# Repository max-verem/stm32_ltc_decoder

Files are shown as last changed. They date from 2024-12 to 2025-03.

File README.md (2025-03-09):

# stm32_ltc_decoder

This device used for decoding LTC from VTRs or other sources. Output sent to CDC serial.

## used parts

### STM32 BluePill board

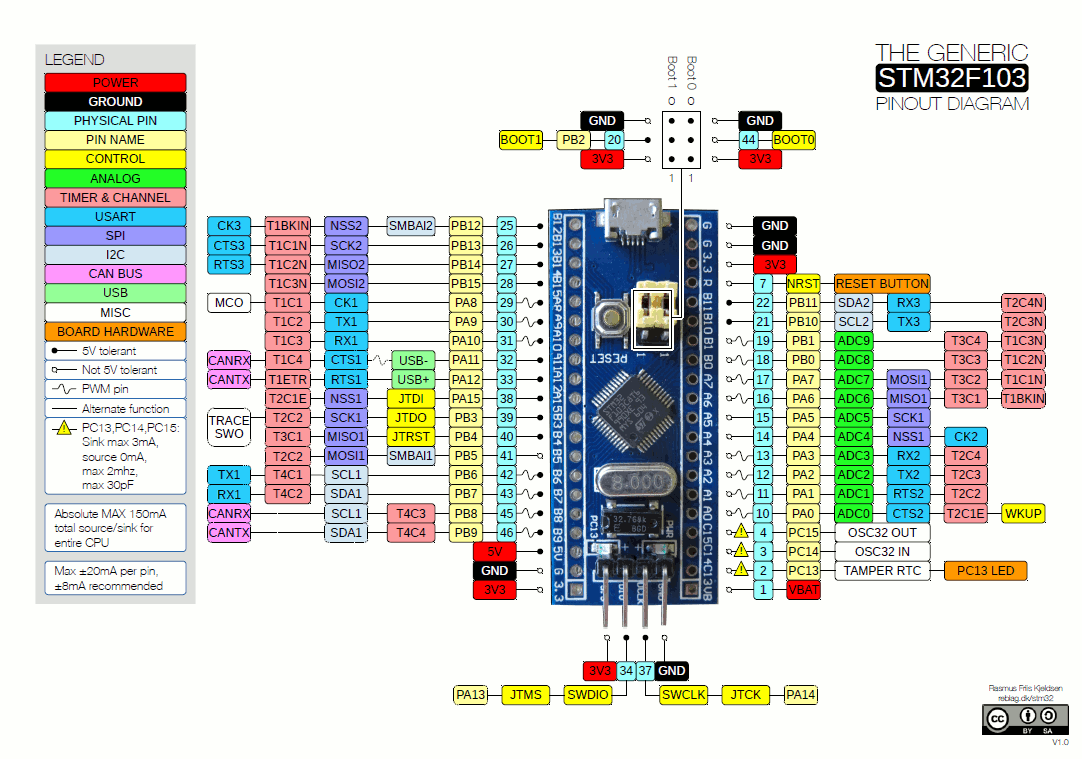
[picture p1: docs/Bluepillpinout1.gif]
STM32 BluePill board


### RS485 module

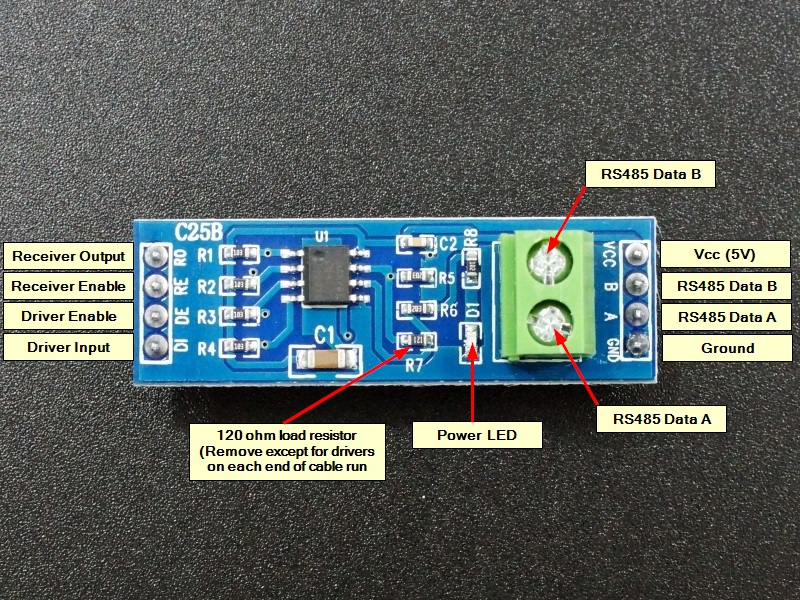
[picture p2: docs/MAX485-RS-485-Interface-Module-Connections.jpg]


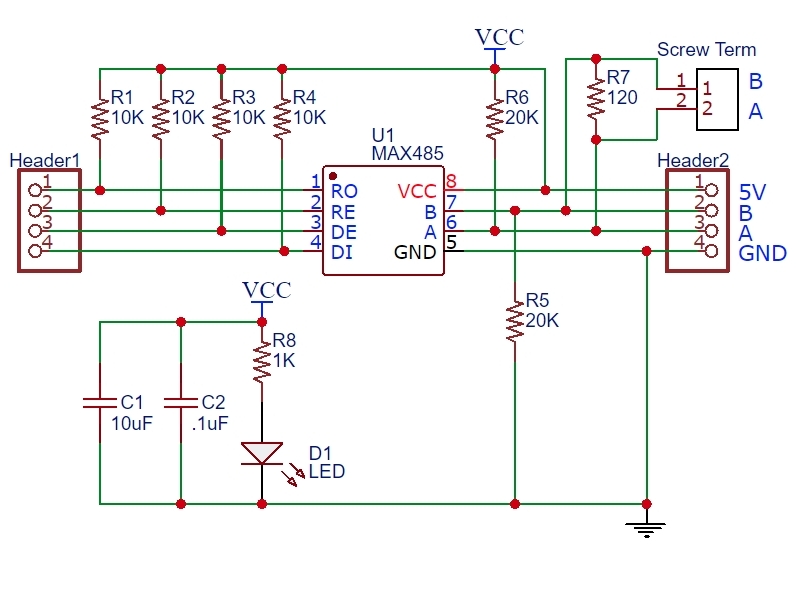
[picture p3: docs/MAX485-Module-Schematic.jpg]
Schematic


Note: **R7** should be removed

### other
* 2N7000
* Jumper
* Prototyping PCB

## connection diagram

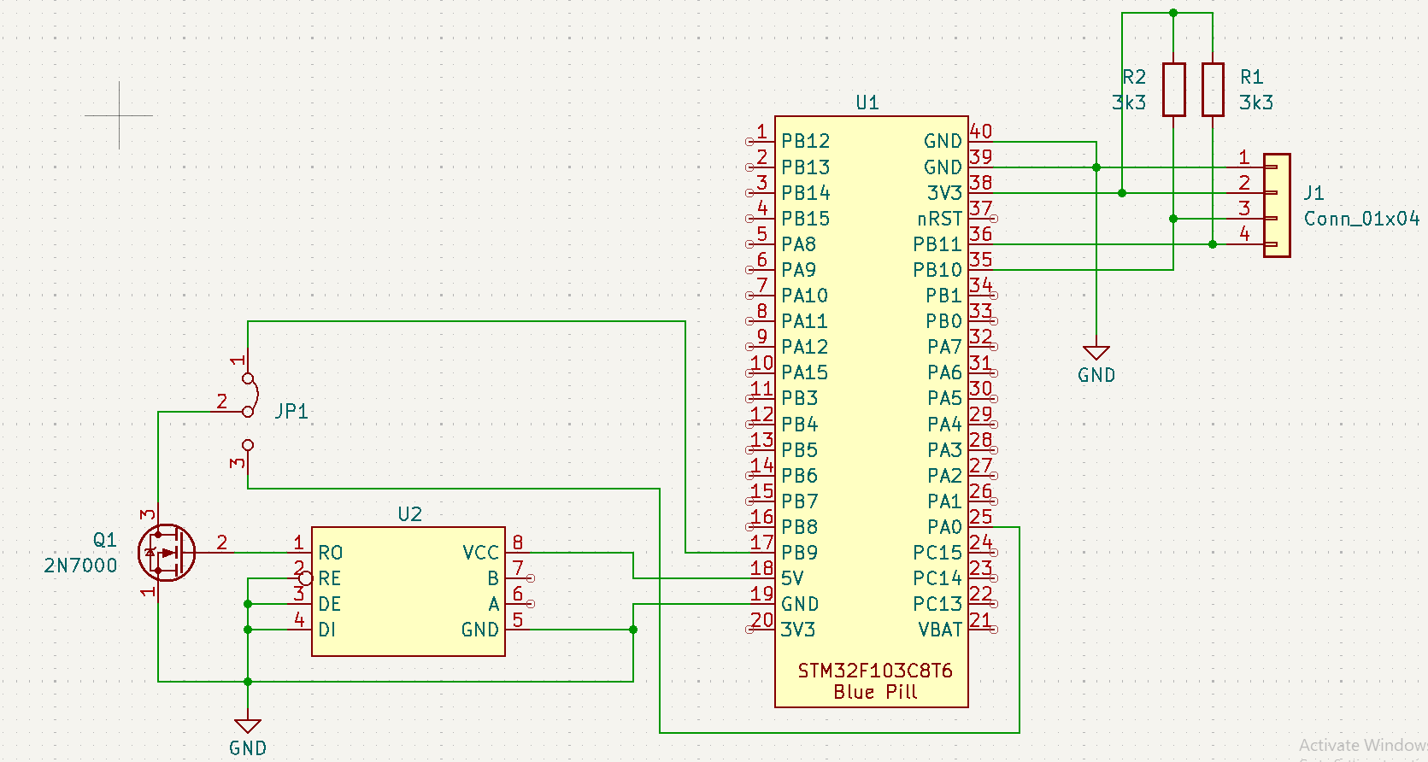
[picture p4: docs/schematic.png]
Schematic


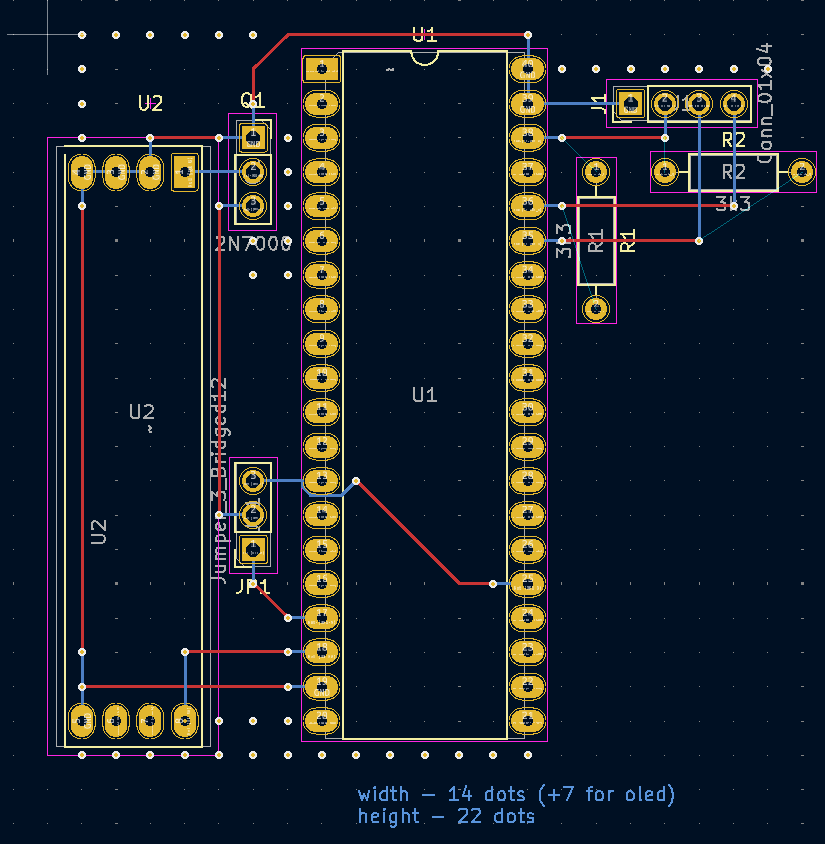
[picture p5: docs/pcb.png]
Perf board


## output example

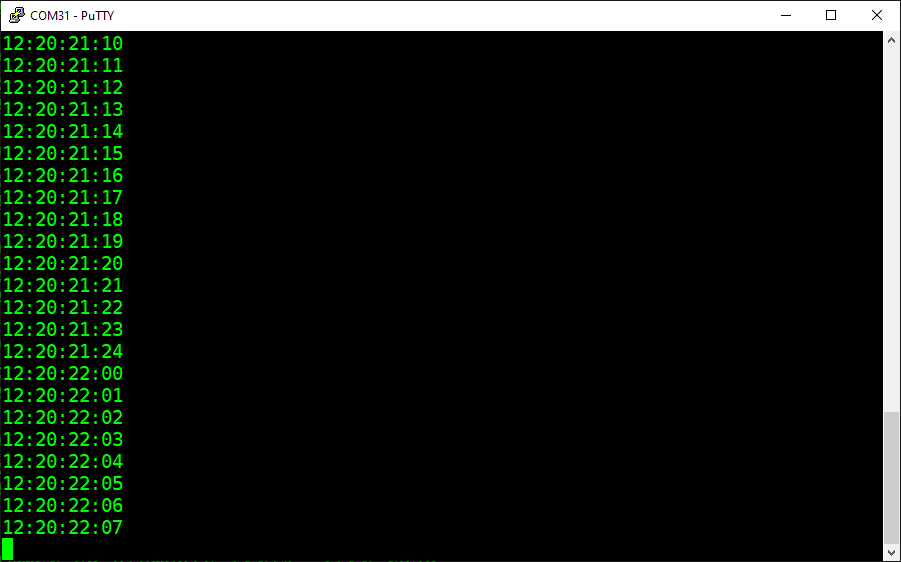
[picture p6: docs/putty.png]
putty


## working model

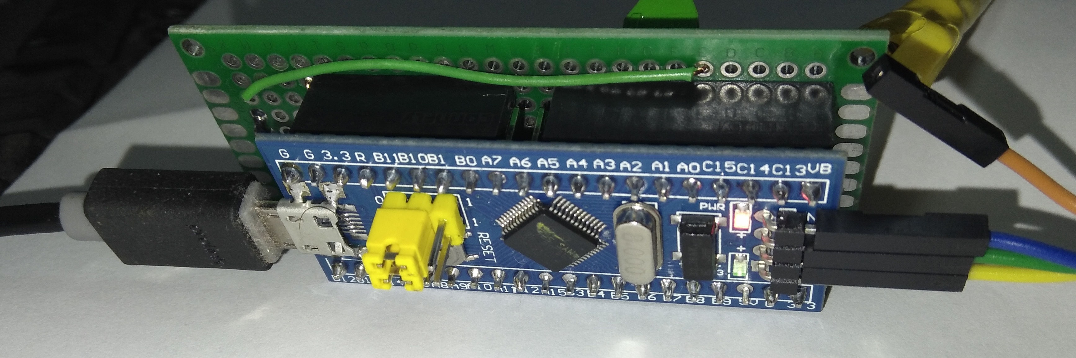
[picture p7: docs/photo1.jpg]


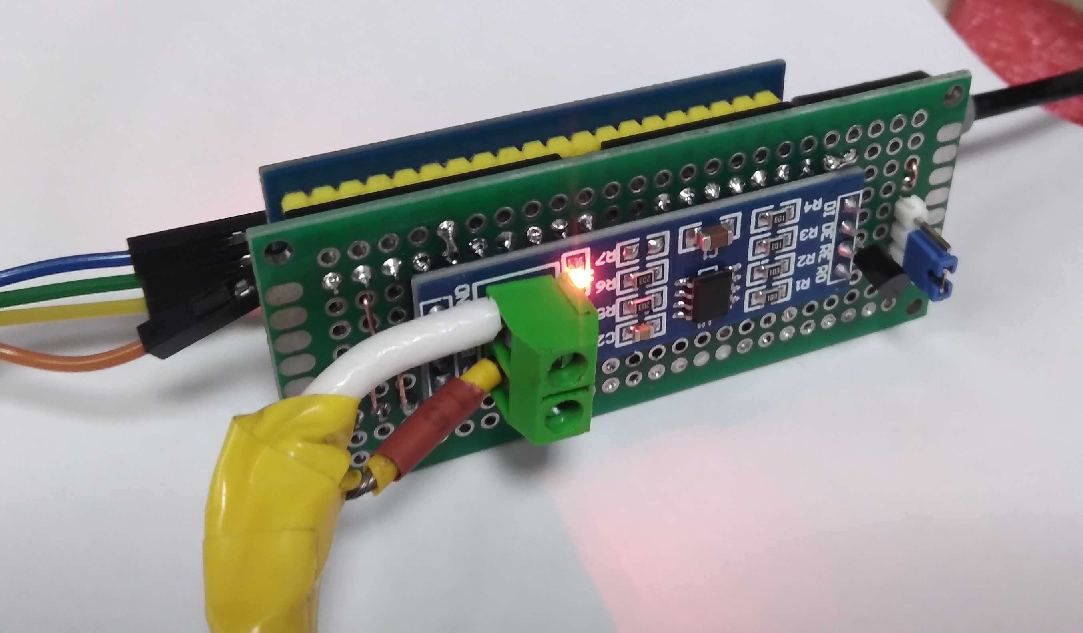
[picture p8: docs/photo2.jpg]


## notes

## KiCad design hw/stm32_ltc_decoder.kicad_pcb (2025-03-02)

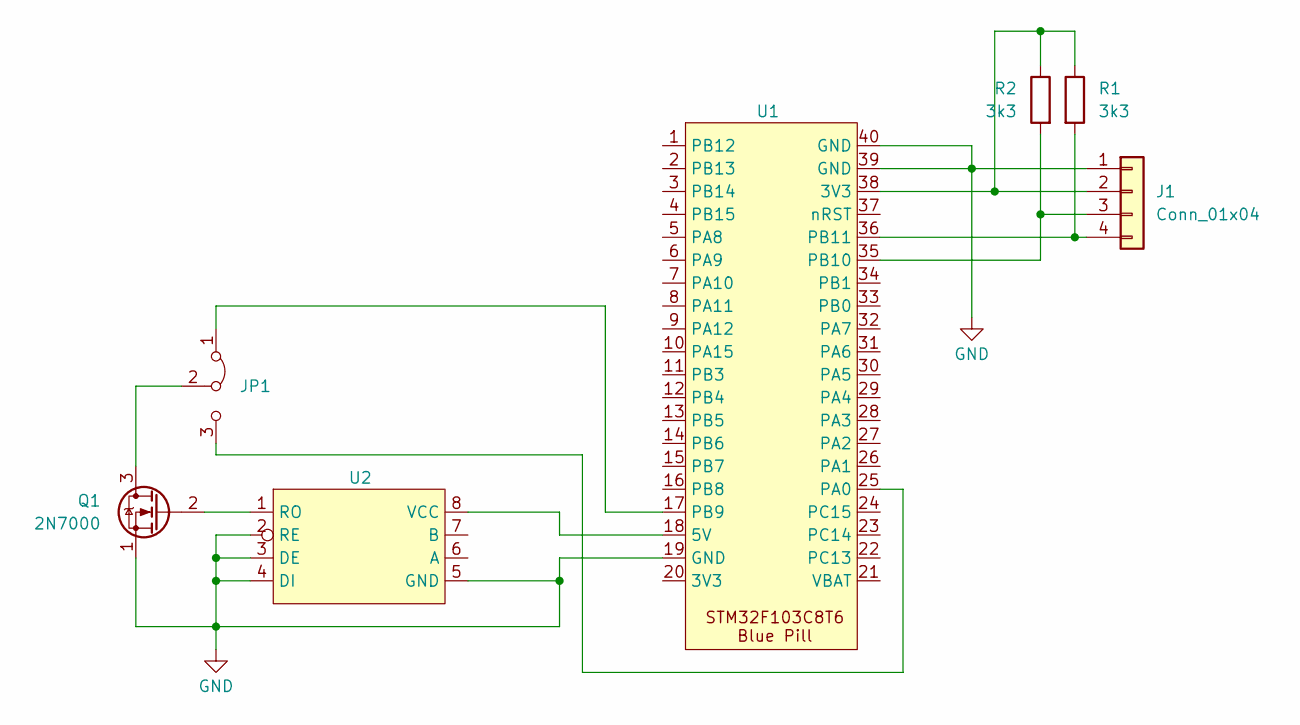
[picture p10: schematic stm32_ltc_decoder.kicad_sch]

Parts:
J1: Conn_01x04; PinHeader_1x04_P2.54mm_Vertical
JP1: Jumper_3_Bridged12; PinSocket_1x03_P2.54mm_Vertical
Q1: 2N7000; PinSocket_1x03_P2.54mm_Vertical
R1, R2: 3k3; R_Axial_DIN0207_L6.3mm_D2.5mm_P10.16mm_Horizontal
U1: BluePill (STM32F103C8T6)
U2: RS485_MODULE

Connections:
GND: J1.1, Q1.1 (S), U1.19 (GND), U1.39 (GND), U1.40 (GND), U2.2 (RE), U2.3 (DE), U2.4 (DI), U2.5 (GND)
unnamed: J1.2, R1.1, R2.1, U1.38 (3V3)
unnamed: J1.3, R2.2, U1.35 (PB10)
unnamed: J1.4, R1.2, U1.36 (PB11)
unnamed: JP1.1 (A), U1.17 (PB9)
unnamed: JP1.3 (B), U1.25 (PA0)
unnamed: JP1.2 (C), Q1.3 (D)
unnamed: Q1.2 (G), U2.1 (RO)
unnamed: U1.18 (5V), U2.8 (VCC)

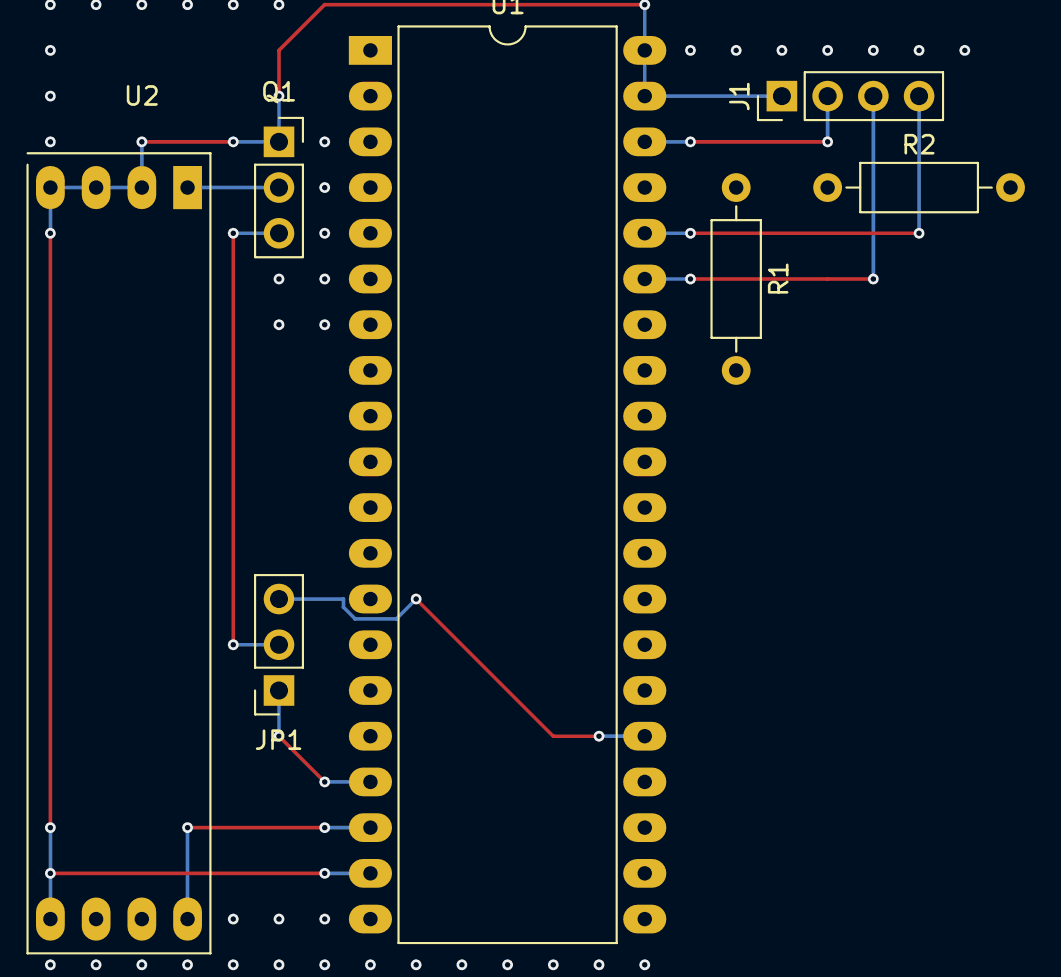
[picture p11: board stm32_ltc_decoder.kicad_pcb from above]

Board: 2 copper layers, 7 parts (0 on the bottom side), 9 nets.

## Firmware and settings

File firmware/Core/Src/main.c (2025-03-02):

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
/* Includes ------------------------------------------------------------------*/
#include "main.h"
#include "dma.h"
#include "i2c.h"
#include "tim.h"
#include "usb_device.h"
#include "gpio.h"

/* USER CODE BEGIN Includes */
#include "usbd_cdc_if.h"
#include "SSD1306.h"
#include "font-14x30.h"
/* USER CODE END Includes */

/* USER CODE BEGIN PM */
#define TC_DISPLAY_UNKNOWN 	0xAAAAAAAA
#define TC_DISPLAY_NONE 	0xFFFFFFFF
/* USER CODE END PM */


/* USER CODE BEGIN PV */

SSD1306_DEF(oled1, hi2c2, SSD1306_I2C_ADDR, 32, 0);

/* USER CODE END PV */

void SystemClock_Config(void);
/* USER CODE BEGIN 0 */
volatile unsigned int ltc_last = 0;
uint32_t tc_display = TC_DISPLAY_UNKNOWN, tc_displayed = TC_DISPLAY_NONE;

#define TIMER1_DIV(DIV) if(!(timer1_cnt % DIV))
#define TIMER1_DIV_BLINK 50
volatile int timer1_cnt = 0;
static void timer1_cb(TIM_HandleTypeDef *htim)
{
	unsigned int now = HAL_GetTick();

	timer1_cnt++;

	/* check if we should solid led if no timecode detected */
	if((ltc_last + 1000) < now)
	{
		HAL_GPIO_WritePin(LED_GPIO_Port, LED_Pin, GPIO_PIN_RESET);
		tc_display = TC_DISPLAY_UNKNOWN;
	}
	else
	{
		/* blink fast it timecode detected */
		TIMER1_DIV(TIMER1_DIV_BLINK)
			HAL_GPIO_TogglePin(LED_GPIO_Port, LED_Pin);
	};
#if 0
	/* this is for debug timer */
	HAL_GPIO_WritePin(SYNC_GPIO_Port, SYNC_Pin, timer1_cnt % 3 ? GPIO_PIN_SET : GPIO_PIN_RESET);
#endif
	SSD1306_refresh(&oled1);
};

// https://habr.com/ru/articles/476582/
// https://community.st.com/t5/stm32-mcus-products/how-do-you-measure-the-execution-cpu-cycles-for-a-section-of/td-p/213709
volatile unsigned int *DWT_CYCCNT   = (volatile unsigned int *)0xE0001004;
volatile unsigned int *DWT_CONTROL  = (volatile unsigned int *)0xE0001000;
volatile unsigned int *DWT_LAR      = (volatile unsigned int *)0xE0001FB0;
volatile unsigned int *SCB_DHCSR    = (volatile unsigned int *)0xE000EDF0;
volatile unsigned int *SCB_DEMCR    = (volatile unsigned int *)0xE000EDFC;
volatile unsigned int *ITM_TER      = (volatile unsigned int *)0xE0000E00;
volatile unsigned int *ITM_TCR      = (volatile unsigned int *)0xE0000E80;

volatile unsigned int ltc_raw[2], ltc_found = 0;

volatile unsigned int bits_buffer[3], bits_count = 0;

#define SYNC_WORD 0xBFFC // 1011 1111 1111 1100

static void probe_ltc()
{
	if(bits_buffer[2] == SYNC_WORD)
	{
		ltc_found = bits_count;
		ltc_raw[0] = bits_buffer[0];
		ltc_raw[1] = bits_buffer[1];
		bits_count = 0;
	}
};

static void push_bit(int b)
{
	if(b == BIT_NONE)
		bits_count = 0;
	else
	{
		// shift
		bits_buffer[0] >>= 1;
		if(bits_buffer[1] & 1) bits_buffer[0] |= 0x80000000;
		bits_buffer[1] >>= 1;
		if(bits_buffer[2] & 1) bits_buffer[1] |= 0x80000000;
		bits_buffer[2] >>= 1;
		if(b == BIT_ONE)
			bits_buffer[2] |= (1 << 15);

		bits_count++;

		if(bits_count >= 80)
			probe_ltc();
	}
};

volatile unsigned int freq_cnt = 0;
volatile unsigned int bit_prev = BIT_NONE;

static void push_tick(unsigned int cnt)
{
	unsigned int dur;

	if(!freq_cnt)
	  freq_cnt = HAL_RCC_GetHCLKFreq() / 1000000;

	dur = cnt / freq_cnt;

	if((BIT_0_DUR - BIT_THRESHOLD) < dur && dur < (BIT_0_DUR + BIT_THRESHOLD))
	{
		bit_prev = BIT_NONE;
		push_bit(BIT_ZERO);
	}
	else if((BIT_1_DUR - BIT_THRESHOLD) < dur && dur < (BIT_1_DUR + BIT_THRESHOLD))
	{
		if(bit_prev)
		{
			bit_prev = BIT_NONE;
			push_bit(BIT_ONE);
		}
		else
			bit_prev = BIT_ONE;
	}
	else
	{
#ifdef DURS_BUF
		durs_buf[durs_idx] = dur; durs_idx = (durs_idx + 1) % DURS_BUF;
#endif
		bit_prev = BIT_NONE;
		push_bit(BIT_NONE);
	}
};

void HAL_GPIO_EXTI_Callback(uint16_t GPIO_Pin)
{
	unsigned int cnt;

	if(GPIO_Pin != LTC_IN_Pin)
		return;

	cnt = *DWT_CYCCNT;
	*DWT_CYCCNT = 0;

	push_tick(cnt);
};

//  https://controllerstech.com/pwm-input-in-stm32/
void HAL_TIM_IC_CaptureCallback(TIM_HandleTypeDef *htim)
{
	if (htim->Channel == HAL_TIM_ACTIVE_CHANNEL_1)
	{
		uint32_t per, high, low;

		// Read the IC value
		per = HAL_TIM_ReadCapturedValue(htim, TIM_CHANNEL_1);
		high = HAL_TIM_ReadCapturedValue(htim, TIM_CHANNEL_2);
		if(per)
		{
			low = per - high;

			push_tick(high);
			push_tick(low);
		}
	}
};

static uint32_t console_font_14x30_transposed[16 /* glyphs */][14 /* width */];

static void console_font_14x30_transpose()
{
	int g;

	for(g = 0; g < 12; g++)
	{
		int w, b, o;
		const uint8_t *src_row = console_font_14x30 + 2 * 30 * g;

		for(w = 0, o = 0, b = 0x80; w < 14; w++, b >>= 1)
		{
			int h;
			uint32_t W = 0;

			if(!b)
			{
				b = 0x80;
				o = 1;
			}

			for(h = 0; h < 30; h++)
				if(src_row[h * 2 + o] & b)
					W |= 1 << h;

			console_font_14x30_transposed[g][w] = W << 4;
		}
	};
}

volatile int semicolon_offset = 3;


/* USER CODE END 0 */

/**
  * @brief  The application entry point.
  * @retval int
  */
int main(void)
{

  /* USER CODE BEGIN 1 */
  unsigned char str[13] = "--:--:--:--\r\n";
  const unsigned char str_map[16] = "0123456789ABCDEF";
  /* USER CODE END 1 */

  /* MCU Configuration--------------------------------------------------------*/

  /* Reset of all peripherals, Initializes the Flash interface and the Systick. */
  HAL_Init();

  /* Configure the system clock */
  SystemClock_Config();

  /* Initialize all configured peripherals */
  MX_GPIO_Init();
  MX_DMA_Init();
  MX_USB_DEVICE_Init();
  MX_TIM2_Init();
  MX_TIM1_Init();
  MX_I2C2_Init();
  /* USER CODE BEGIN 2 */

  // setup and init oled display
  console_font_14x30_transpose();
  SSD1306_setup(&oled1);

  // https://habr.com/ru/articles/476582/
  // https://community.st.com/t5/stm32-mcus-products/how-do-you-measure-the-execution-cpu-cycles-for-a-section-of/td-p/213709
  *SCB_DEMCR |= 0x01000000;
  *DWT_LAR = 0xC5ACCE55; // enable access
  *DWT_CYCCNT = 0; // reset the counter
  *DWT_CONTROL |= 1 ; // enable the counter

  // start timer
  HAL_TIM_RegisterCallback(&htim1, HAL_TIM_PERIOD_ELAPSED_CB_ID, timer1_cb);
  HAL_TIM_Base_Start_IT(&htim1);

  // start PWM counters
  HAL_TIM_IC_Start_IT(&htim2, TIM_CHANNEL_1);
  HAL_TIM_IC_Start(&htim2, TIM_CHANNEL_2);

  /* USER CODE END 2 */

  /* Infinite loop */
  /* USER CODE BEGIN WHILE */
  while (1)
  {

	  if(ltc_found == 80)
	  {
		  uint32_t tc = 0;

		  ltc_found = 0;

		  tc |= (ltc_raw[0] & 0x0000000F) >> 0;
		  tc |= (ltc_raw[0] & 0x00000300) >> 4;
		  tc |= (ltc_raw[0] & 0x000F0000) >> 8;
		  tc |= (ltc_raw[0] & 0x07000000) >> 12;

		  tc |= (ltc_raw[1] & 0x0000000F) << 16;
		  tc |= (ltc_raw[1] & 0x00000700) << 12;
		  tc |= (ltc_raw[1] & 0x000F0000) << 8;
		  tc |= (ltc_raw[1] & 0x03000000) << 4;

		  tc_display = tc;

		  str[10] = str_map[ tc & 0x0F ]; tc >>= 4;
		  str[ 9] = str_map[ tc & 0x0F ]; tc >>= 4;
		  str[ 7] = str_map[ tc & 0x0F ]; tc >>= 4;
		  str[ 6] = str_map[ tc & 0x0F ]; tc >>= 4;
		  str[ 4] = str_map[ tc & 0x0F ]; tc >>= 4;
		  str[ 3] = str_map[ tc & 0x0F ]; tc >>= 4;
		  str[ 1] = str_map[ tc & 0x0F ]; tc >>= 4;
		  str[ 0] = str_map[ tc & 0x0F ]; tc >>= 4;

		  ltc_last = HAL_GetTick();

		  CDC_Transmit_FS(str, sizeof(str));

	  }

	  if(tc_display != tc_displayed && !oled1.dirty && !oled1.busy)
	  {
		  uint32_t bcd;
		  int i = 0, j, s;
#if 1
		  /* this is for estimating display rendering time */
		  HAL_GPIO_WritePin(SYNC_GPIO_Port, SYNC_Pin, GPIO_PIN_SET);
#endif
		  bcd = tc_display;
		  tc_displayed = tc_display;

		  for(j = 0, s = 28; j < 8; j++, s -= 4)
		  {
			  int w, g;

			  // spacer
			  if(j && !(j & 1))
			  for(w = 0; w < 5; w++, i++)
			  {
				  uint32_t W = console_font_14x30_transposed[11 /* glyphs */][w + semicolon_offset /* width */];

				  oled1.fb[0][SSD1306_DATA_OFFSET + i] = W >>  0;
				  oled1.fb[1][SSD1306_DATA_OFFSET + i] = W >>  8;
				  oled1.fb[2][SSD1306_DATA_OFFSET + i] = W >> 16;
				  oled1.fb[3][SSD1306_DATA_OFFSET + i] = W >> 24;
			  }

			  // find glyph index
			  g = bcd >> s;
			  g &= 0x0F;
			  if(g > 10) g = 10;

			  // copy glyph bitmap data
			  for(w = 0; w < 14; w++, i++)
			  {
				  uint32_t W = console_font_14x30_transposed[g /* glyphs */][w /* width */];

				  oled1.fb[0][SSD1306_DATA_OFFSET + i] = W >>  0;
				  oled1.fb[1][SSD1306_DATA_OFFSET + i] = W >>  8;
				  oled1.fb[2][SSD1306_DATA_OFFSET + i] = W >> 16;
				  oled1.fb[3][SSD1306_DATA_OFFSET + i] = W >> 24;
			  }
		  }

		  // mark page dirty
		  oled1.dirty = 0x0f;
#if 1
		  /* this is for estimating display rendering time */
		  HAL_GPIO_WritePin(SYNC_GPIO_Port, SYNC_Pin, GPIO_PIN_RESET);
#endif
	  }


    /* USER CODE END WHILE */

    /* USER CODE BEGIN 3 */
  }
  /* USER CODE END 3 */
}

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


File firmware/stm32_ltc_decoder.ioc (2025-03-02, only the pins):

Mcu.UserName=STM32F103C8Tx
PA0-WKUP.Signal=S_TIM2_CH1_ETR
PA11.Signal=USB_DM
PA12.Signal=USB_DP
PA13.Signal=SYS_JTMS-SWDIO
PA14.Signal=SYS_JTCK-SWCLK
PB10.Signal=I2C2_SCL
PB11.Signal=I2C2_SDA
PB8.GPIO_Label=SYNC
PB8.Signal=GPIO_Output
PB9.GPIO_Label=LTC_IN
PB9.Signal=GPXTI9
PC13-TAMPER-RTC.GPIO_Label=LED
PC13-TAMPER-RTC.Signal=GPIO_Output
PC14-OSC32_IN.Signal=RCC_OSC32_IN
PC15-OSC32_OUT.Signal=RCC_OSC32_OUT
PD0-OSC_IN.Signal=RCC_OSC_IN
PD1-OSC_OUT.Signal=RCC_OSC_OUT

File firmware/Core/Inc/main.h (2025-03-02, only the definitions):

#define TIMER1_PRESCALER_RAW 48
#define TIMER1_PERIOD_RAW 1000
#define TIMER1_PRESCALER (TIMER1_PRESCALER_RAW - 1)
#define TIMER1_PERIOD (TIMER1_PERIOD_RAW - 1)
#define LED_Pin GPIO_PIN_13
#define LED_GPIO_Port GPIOC
#define SYNC_Pin GPIO_PIN_8
#define SYNC_GPIO_Port GPIOB
#define LTC_IN_Pin GPIO_PIN_9
#define LTC_IN_GPIO_Port GPIOB
#define LTC_IN_EXTI_IRQn EXTI9_5_IRQn

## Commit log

2025-03-02 Schematic and source code updated
    [stm32_ltc_decoder.kicad_pcb, stm32_ltc_decoder.kicad_sch]
2025-03-09 Add padding to framebuffer bank/row/line
2025-03-09 Update schematic for connector porpose
    [stm32_ltc_decoder.kicad_sch]
